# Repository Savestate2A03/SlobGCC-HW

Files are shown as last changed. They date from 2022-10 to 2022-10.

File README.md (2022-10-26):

# SlobGCC-HW
Separate repository for the hardware used in the SlobGCC, a modified PhobGCC for back-mounting Teensys.
Also note the Teensy is a little lower than usual

## Images and Notes
This is my first time ever using a PCB software so I hope I didn't screw anything up.

### Front


### Back


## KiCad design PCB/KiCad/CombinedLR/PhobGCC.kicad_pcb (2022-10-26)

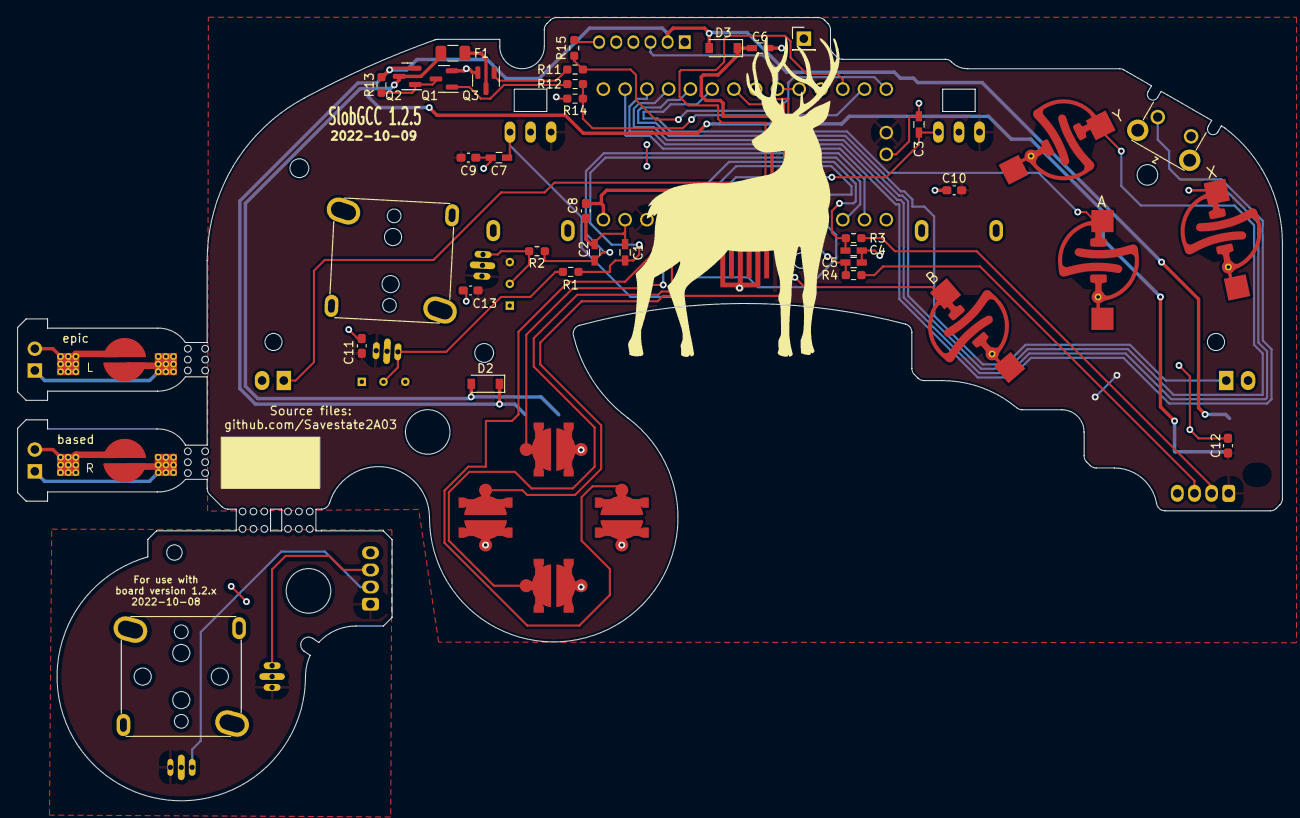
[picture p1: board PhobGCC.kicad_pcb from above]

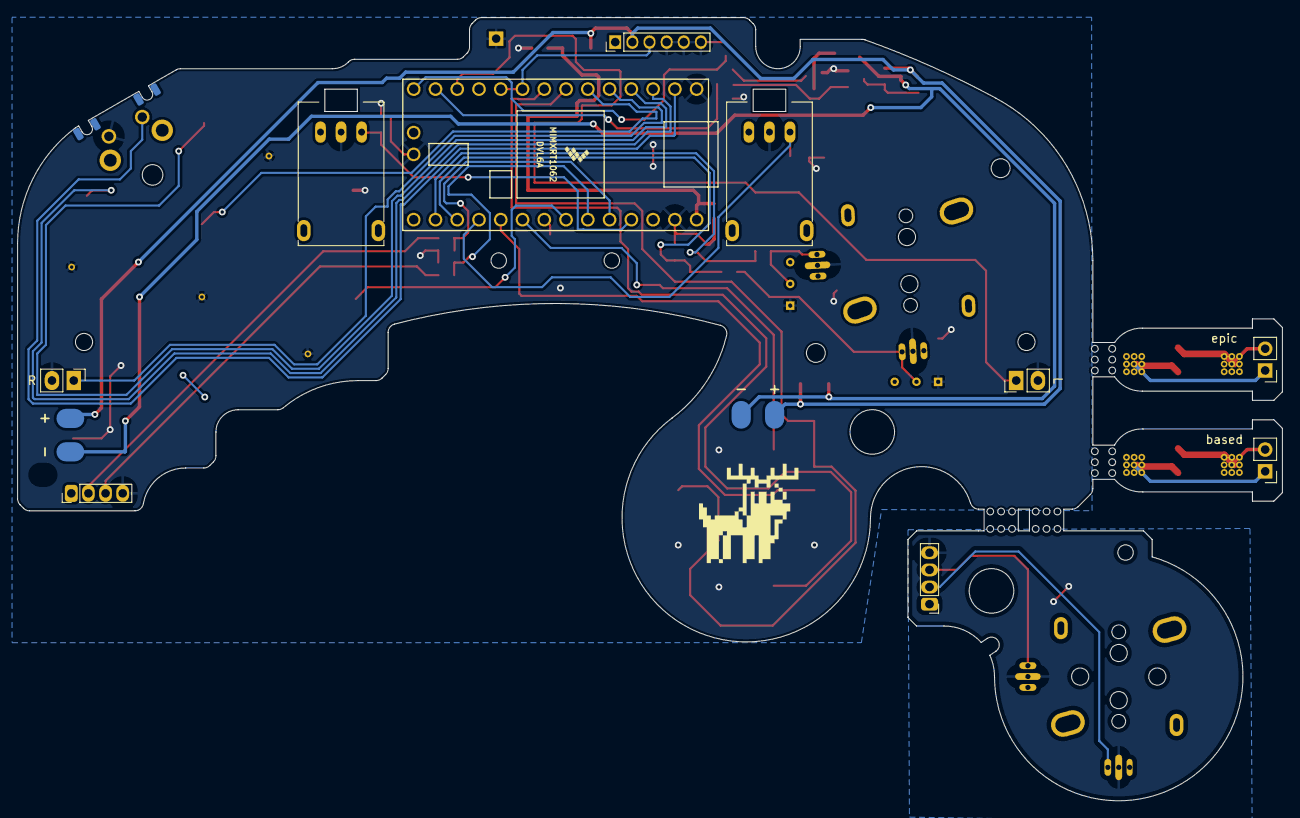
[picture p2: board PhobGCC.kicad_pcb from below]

Board: 2 copper layers, 147.6 x 91.4 mm, 75 parts (12 on the bottom side), 41 nets.

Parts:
C1, C2, C3, C4, C5, C7: 0.047u; C_0603_HandSoldering
C6: 10u; C_0603_HandSoldering
C8, C9, C10, C11, C12, C13: 1u; C_0603_1608Metric_Pad1.08x0.95mm_HandSolder
D2, D3: M7C; D_SOD-123
F1: Fuse; Fuse_1206_3216Metric
G10: LOGO; deerbig
H1: 5.2mm; MountingHole_5.2mm
H2: Slot
H3, H4: 2mm; MountingHole_2.0mm
H5, H6: 1.8mm; MountingHole_1.8mm
H7: 2.4mm; MountingHole_2.4mm
H8, H9: 2.2mm; MountingHole_2.2mm
H10: MountingHole; MountingHole_1.8mm
H11: MountingHole; MountingHole_5.2mm
H12, H13: MountingHole; MountingHole_2.0mm
H14, H15: MouseBite; breakaway-mousebites-double
H16: MouseBiteLA; breakaway-mousebites-double
H17: MouseBiteRA; breakaway-mousebites-double
J1: Conn_01x06_Female; GCC_Header_Straight_1x06_Pitch2.00mm
J2: Conn_01x04_Female; PinHeader_1x04_P2.00mm_Vertical
J3: Conn_01x01_Male; PinHeader_1x01_P2.54mm_Vertical
J4: Conn_01x04_Male; PinHeader_1x04_P2.00mm_Vertical
J5, J5#2: Rumble; rumble_pins
J6: L; Pin_Header_Straight_1x02_Pitch2.54mm
J7: R; Pin_Header_Straight_1x02_Pitch2.54mm
Q1, Q3: Q_NMOS_GSD; SOT-23
Q2: Q_PMOS_GDS; SOT-23
R1, R2, R3, R4: 2k; R_0603_1608Metric_Pad0.98x0.95mm_HandSolder
R11, R12: 100R; R_0603_1608Metric_Pad0.98x0.95mm_HandSolder
R13, R14, R15: 10k; R_0603_1608Metric_Pad0.98x0.95mm_HandSolder
RV1, RV2: R_POT_MountingPin; GCC_Slider
SW1: A; ABXY_Contact_Omron_Switch
SW2: B; ABXY_Contact_Omron_Switch
SW3: X; ABXY_Contact_Omron_Switch
SW4: Y; ABXY_Contact_Omron_Switch
SW5: Start; Start_Contact
SW6: L; Pin_Header_Straight_1x02_Pitch2.54mm
SW7: R; Pin_Header_Straight_1x02_Pitch2.54mm
SW8: Z; Z_Switch_Edge_Omron
SW9: Dleft; Dpad_Contact_TL3315NF_2
SW10: Dup; Dpad_Contact_TL3315NF_2
SW11: Dright; Dpad_Contact_TL3315NF_2
SW12: Ddown; Dpad_Contact_TL3315NF_2
SW13: L; Trigger_Contact
SW14: R; Trigger_Contact
TSTP1, TSTP2: testing pads
U1: Teensy4.0; Teensy40_Edge_Pins
U2: 2x DRV5053CAQLPGM Hall Effect Sensors; GCC_Stickbox_2
U5: Stickbox_Assembly; GCC_Stickbox_Hall_Only

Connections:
+3V3: C9.1, C10.1, C11.1, C12.1, C13.1, J2.1, RV1.1 (V+), RV2.1 (V+), TSTP1.3, TSTP2.3, U1.16 (3V3), U1.31 (3V3), U2.1 (H1XV), U2.4 (H1YV)
+5V: D2.1 (K), D3.2 (A), J1.2, J5.1, J5#2.1, Q2.2 (S), R13.2
/A: SW1.1, U1.6 (4_BCLK2)
/B: SW2.1, U1.27 (20_A6_TX5_LRCLK1)
/Brake: R12.1, R14.2, U1.13 (11_MOSI_CTX1)
/C_x: J2.2, R3.2
/C_x_filt: C4.1, R3.1, U1.29 (22_A8_CTX1)
/C_y: J2.3, R4.2
/C_y_filt: C5.1, R4.1, U1.28 (21_A7_RX5_BCLK1)
/Data: J1.3, U1.9 (7_RX2_OUT1A), U1.10 (8_TX2_IN1)
/Ddown: SW12.1, U1.8 (6_OUT1D)
/Dleft: SW9.1, U1.24 (17_A3_TX4_SDA1)
/Dright: SW11.1, U1.7 (5_IN2)
/Dup: SW10.1, U1.25 (18_A4_SDA0)
/L: SW6.1, U1.12 (10_CS_MQSR)
/Lanalog: C7.1, RV1.3 (Signal), U1.23 (16_A2_RX4_SCL1)
/R: SW7.1, U1.5 (3_LRCLK2)
/Ranalog: C3.1, RV2.3 (Signal), U1.30 (23_A9_CRX1_MCLK1)
/Rumble: R11.1, R15.2, U1.14 (12_MISO_MQSL)
/Start: SW5.1, U1.26 (19_A5_SCL0)
/Stick_x: R1.2, TSTP1.2, U2.3 (H1XS)
/Stick_x_filt: C1.1, R1.1, U1.22 (15_A1_RX3_SPDIF_IN)
/Stick_y: R2.2, TSTP2.2, U2.6 (H1YS)
/Stick_y_filt: C2.1, R2.1, U1.21 (14_A0_TX3_SPDIF_OUT)
/X: SW3.1, U1.3 (1_TX1_CTX2_MISO1)
/Y: SW4.1, U1.4 (2_OUT2)
/Z: SW8.1, U1.2 (0_RX1_CRX2_CS1)
GND: C1.2, C2.2, C3.2, C4.2, C5.2, C6.2, C7.2, C8.2, C9.2, C10.2, C11.2, C12.2, C13.2, J1.4, J1.5, J1.6, J2.4, J3.1, J4.4, Q1.2 (S), Q3.2 (S), R14.1, R15.1, RV1.2 (GND), RV2.2 (GND), SW1.2, SW2.2, SW3.2, SW4.2, SW5.2, SW6.2, SW7.2, SW8.2, SW9.2, SW10.2, SW11.2, SW12.2, TSTP1.1, TSTP2.1, U1.1 (GND), U1.17 (GND), U1.32 (GND), U2.2 (H1XG), U2.5 (H1YG), U5.2 (H1XG), U5.5 (H1YG)
unnamed: C6.1, C8.1, D3.1 (K), U1.33 (VIN)
unnamed: D2.2 (A), F1.1, J5.2, J5#2.2, Q2.3 (D)
unnamed: F1.2, Q3.3 (D)
unnamed: J4.2, U5.3 (H1XS)
unnamed: J4.3, U5.6 (H1YS)
unnamed: J6.1, SW13.1
unnamed: J6.2, SW13.2
unnamed: J7.1, SW14.1
unnamed: J7.2, SW14.2
unnamed: Q1.1 (G), R12.2
unnamed: Q1.3 (D), Q2.1 (G), R13.1
unnamed: Q3.1 (G), R11.2
VCC: J4.1, U5.1 (H1XV), U5.4 (H1YV)

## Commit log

2022-10-06 SlobGCC 1.2.3, back mounted teensy
    [Board Outline.DXF, CStick.kicad_pcb, CStick.kicad_sch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]
2022-10-06 1.2.3 with fixed ground pin
    [PhobGCC.kicad_pcb, PhobGCC.kicad_sch]
2022-10-06 moved teensy down a bit
    [PhobGCC.kicad_pcb]
2022-10-06 Update with image of lower Teensy
2022-10-09 remake based on 1.2.4
    [PhobGCC.kicad_pcb]
2022-10-14 move teensy down
    [PhobGCC.kicad_pcb]
2022-10-14 make back deer smaller
    [PhobGCC.kicad_pcb]
2022-10-14 remove errant text
    [PhobGCC.kicad_pcb]
2022-10-14 move teeensy down even a touch more
    [PhobGCC.kicad_pcb]
2022-10-14 add 2nd rumble pad for dual handle cell rumble
    [PhobGCC.kicad_pcb]
2022-10-26 1.2.5 (double rumble, silkscreen edits)
    [PhobGCC.kicad_pcb]
